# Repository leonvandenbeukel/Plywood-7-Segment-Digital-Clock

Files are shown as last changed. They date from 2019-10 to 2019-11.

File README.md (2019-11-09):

# Plywood 7 Segment Digital Clock

Design is done with [FreeCAD](https://www.freecadweb.org/) (Plywood-7-Segment-Digital-Clock.FCStd). This file contains all the source models for 3D printing and the paths for CNC machining (you might have to re-create the paths for your CNC machine but you can use the FreeCAD file for this). My paths are generated to use with a [GRBL](https://github.com/gnea/grbl/wiki) based machine.

## License

<br />This work is licensed under a <a rel="license" href="http://creativecommons.org/licenses/by-nc-sa/4.0/">Creative Commons Attribution-NonCommercial-ShareAlike 4.0 International License</a>.

## Schematic

Connect 5 volts from the micro usb breakout board to the 5 volt (VIN) pin on the ESP module.  
Connect Ground from the micro usb breakout board to the Ground on the ESP module.  
Connect 5 volts from the usb breakout board to 5 volt on the LED strip.  
Connect Ground from the usb breakout board to Ground on the LED strip.  
Connect pin D6 from the ESP module to the Data line on the LED strip.  
Connect pin D8 from the ESP module to one side of the button and connect the other side of the button to 3.3V of the ESP module.  

To power the clock you can use a regular 5V 2A power supply.

| Components                   |
| -------------                |
| ESP8266 Wi-Fi module         |
| USB break out board          |
| 5V 2A power supply           |
| Wires                        |
| Mini breadboard              |
| 58x WS2812B LED              |

## Indexes of LEDs (2 per segment):

Check the YouTube video for the order how to wire and solder them together because this is mirrored to the following diagram:

```

    47 46        33 32            17 16        3  2
  48     45    34     31        18     15    4      1
  49     44    35     30   29   19     14    5      0
    57 56        43 42            27 26       13 12
  50     55    36     41   28   20     25    6     11
  51     54    37     40        21     24    7     10 
    52 53        38 39            22 23        8  9
    
```

## YouTube video

<a href="https://youtu.be/EQGggxqPL-g" target="_blank">Click to view: Plywood Clock</a>

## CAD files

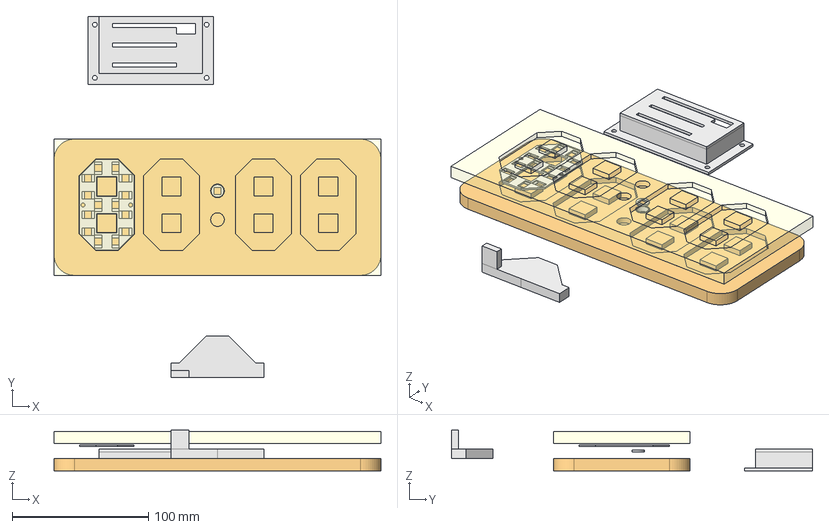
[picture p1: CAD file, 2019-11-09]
Plywood-7-Segment-Digital-Clock.FCStd
240.0 x 265.0 x 30.0 mm
Front panel
3DP dot insert
3DP dot back panel
3DP segments back panel
Board Mount
Back cover

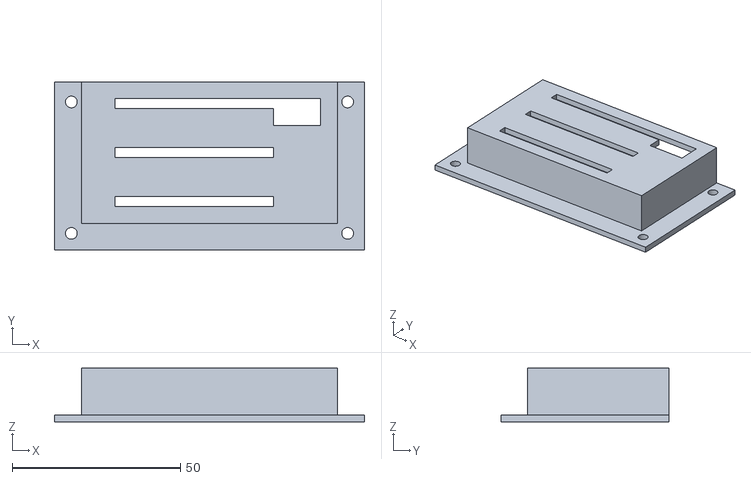
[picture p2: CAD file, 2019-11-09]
stl/board back panel.stl
92.0 x 50.0 x 16.0

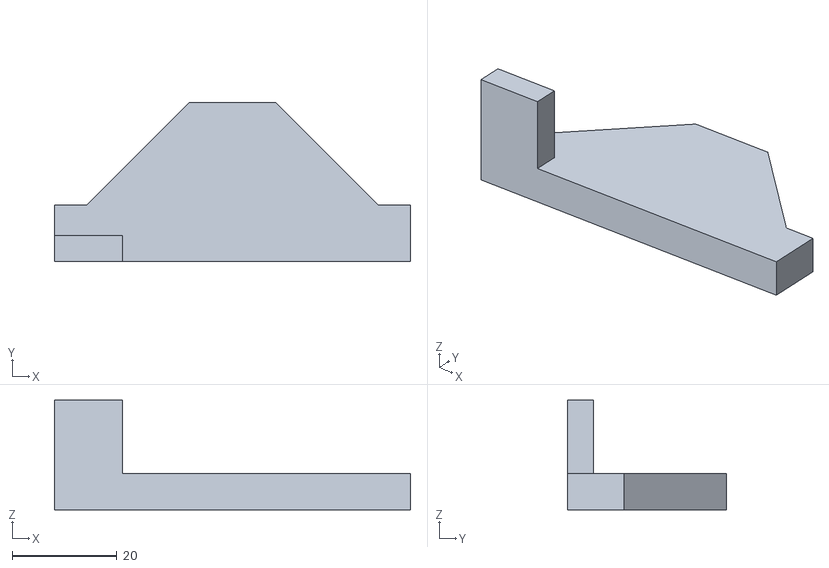
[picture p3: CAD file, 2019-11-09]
stl/board mount.stl
68.0 x 30.4 x 21.0

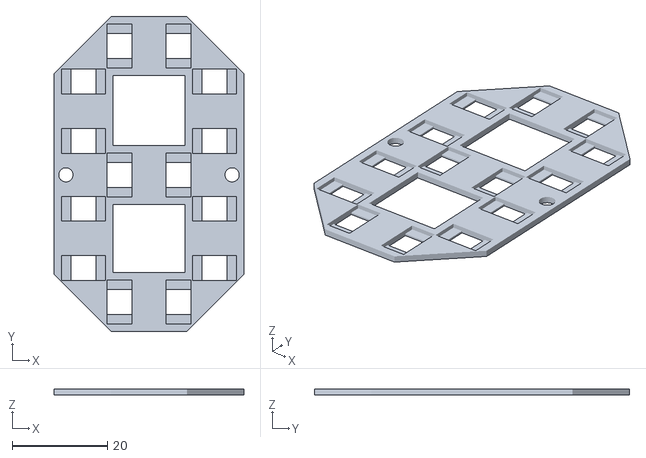
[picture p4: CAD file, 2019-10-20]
stl/segments back.stl
39.9 x 66.3 x 1.20

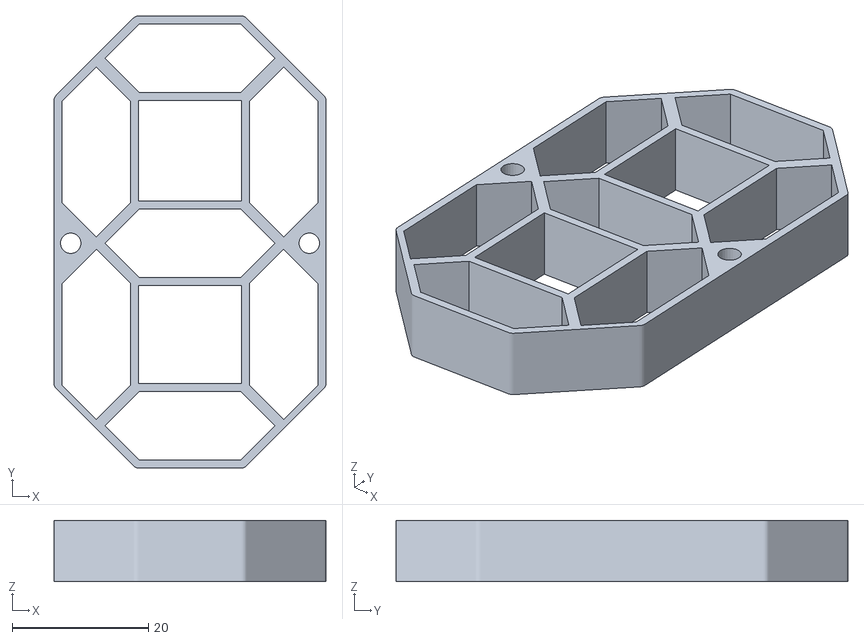
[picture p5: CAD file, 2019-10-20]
stl/segments.stl
39.9 x 66.3 x 9.00

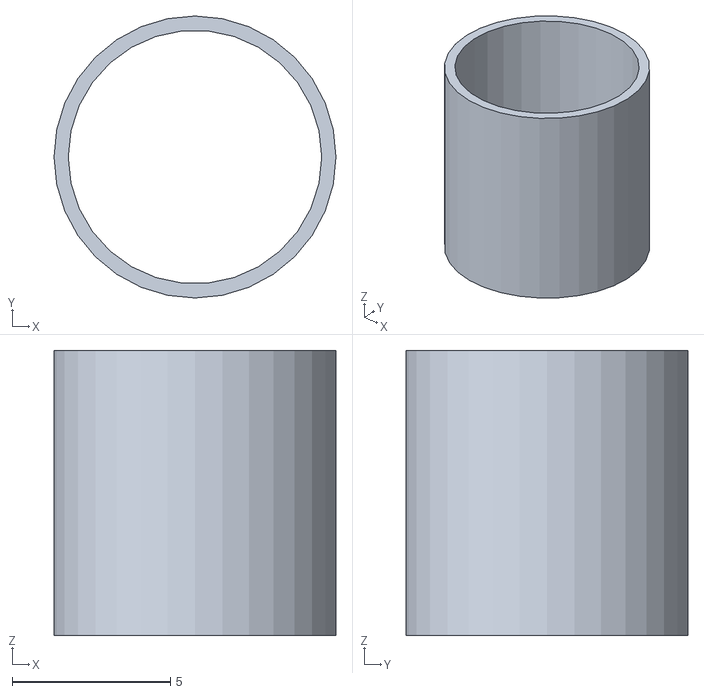
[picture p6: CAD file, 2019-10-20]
stl/dot insert.stl
8.90 x 8.90 x 9.00

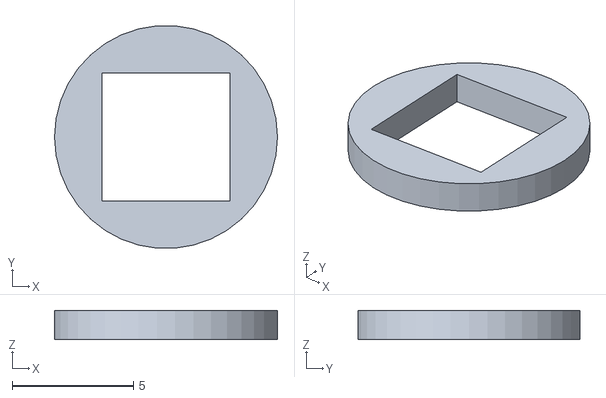
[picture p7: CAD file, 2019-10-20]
stl/dot insert back.stl
9.20 x 9.17 x 1.20

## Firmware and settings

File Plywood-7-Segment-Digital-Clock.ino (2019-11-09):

/*
  
 Leon van den Beukel - 2019 

 Licence: Attribution-NonCommercial-ShareAlike 4.0 International (CC BY-NC-SA 4.0) (https://creativecommons.org/licenses/by-nc-sa/4.0/)
    
*/

#include <ESP8266WiFi.h>
#include <WiFiClient.h>
#include <time.h>
#include <FastLED.h>
#include <EEPROM.h>

const char *WIFI_NETWORK_NAME = "***";              // Change to your wifi network name
const char *WIFI_PASSWORD = "***";                  // Change to your wifi password
float timeZone = 1.0;                               // Change this value to your local timezone (in my case +1 for Amsterdam)
const int DAY_LIGHT_OFFSET_SECONDS = 3600;          // Daylight saving

const char *TIME_SERVER = "pool.ntp.org";
const int EPOCH_1_1_2019 = 1546300800;
time_t now;

#define NUM_LEDS 58
#define DATA_PIN 6 
CRGB LEDs[NUM_LEDS];

byte nrOfLEDsPerSegment = 2;
void displayNumber(byte, byte);
void displayDots();

#define BTN_PIN D8

#define arr_len( x )  ( sizeof( x ) / sizeof( *x ) )
CRGB colors[] = {CRGB::Red, CRGB::RoyalBlue, CRGB::Green, CRGB::Yellow, CRGB::Magenta, CRGB::White, CRGB::Blue};
byte colorSize = arr_len(colors);
byte colorIndex = 0;
CRGB color = colors[colorIndex];

void setup() { 

  pinMode(BTN_PIN, INPUT);

  // Initialize LED strip
  FastLED.delay(2000);
  
  // Check if you're LED strip is a RGB or GRB version (third parameter)
  FastLED.addLeds<WS2812B, DATA_PIN, GRB>(LEDs, NUM_LEDS);

  Serial.begin(115200);          
  
  WiFi.begin(WIFI_NETWORK_NAME, WIFI_PASSWORD);

  while (WiFi.status() != WL_CONNECTED)
  {
    delay(500);
    Serial.print(".");
  }

  configTime(timeZone, DAY_LIGHT_OFFSET_SECONDS, TIME_SERVER);

  while (now < EPOCH_1_1_2019)
  {
    now = time(nullptr);
    delay(500);
    Serial.print("*");
  }

  // If color is stored previously, than restore
  EEPROM.begin(1);
  colorIndex = EEPROM.read(0);
  if (colorIndex >= 0) {
    color = colors[colorIndex];
    Serial.print("Previous color found: ");
    Serial.println(colorIndex);
  } else {
    Serial.print("Previous color not found: ");
    Serial.println(colorIndex);
  }
}

void loop() {

  int buttonState = digitalRead(BTN_PIN);
  if (buttonState == HIGH) {
    Serial.println("Button Pushed");
    colorIndex += 1;
    if (colorIndex >= colorSize)
      colorIndex = 0;
    
    color = colors[colorIndex];
    
    EEPROM.write(0, colorIndex); 
    EEPROM.end();
    Serial.print("Color index stored: ");
    Serial.println(colorIndex);  
  }

  struct tm *timeinfo;
  time(&now);
  timeinfo = localtime(&now);

  int hour = timeinfo->tm_hour;
  int mins = timeinfo->tm_min;

  byte h1 = hour / 10;
  byte h2 = hour % 10;
  byte m1 = mins / 10;
  byte m2 = mins % 10;

  displayDots();
  
  if (h1 > 0)
    displayNumber(h1,3);
    
  displayNumber(h2,2);
  displayNumber(m1,1);
  displayNumber(m2,0);

  delay(150);
}

void displayNumber(byte number, byte segment) {

  // segment from left to right: 3, 2, 1, 0
  byte startindex = 0;
  switch (segment) {
    case 0:
      startindex = 0;
      break;
    case 1:
      startindex = 14;
      break;
    case 2:
      startindex = 30;
      break;
    case 3:
      startindex = 44;
      break;    
  }

/*

Indexes of LEDs (2 per segment):

    47 46        33 32            17 16        3  2
  48     45    34     31        18     15    4      1
  49     44    35     30   29   19     14    5      0
    57 56        43 42            27 26       13 12
  50     55    36     41   28   20     25    6     11
  51     54    37     40        21     24    7     10 
    52 53        38 39            22 23        8  9
    
*/

  int numbers[] = {
    0b00111111111111,  // 0
    0b00110000000011,  // 1
    0b11001111001111,  // 2
    0b11111100001111,  // 3
    0b11110000110011,  // 4
    0b11111100111100,  // 5
    0b11111111111100,  // 6
    0b00110000001111,  // 7
    0b11111111111111,  // 8
    0b11111100111111,  // 9
    0b00000000000000,  // 10 off       
  };

  for (byte i=0; i<14; i++){
    LEDs[i + startindex] = ((numbers[number] & 1 << i) == 1 << i) ? color : CRGB::Black;
  }

  FastLED.show();  
}

void allOff() {

  for (int i=0; i<NUM_LEDS; i++){
    LEDs[i] = CRGB::Black;
  }
  FastLED.show();
  
}

void allOn(CRGB color) {

  for (int i=0; i<NUM_LEDS; i++){
    LEDs[i] = color;
  }
  FastLED.show();
  
}

void displayDots() {
   LEDs[28] = color;
   LEDs[29] = color;    
   FastLED.show();
}

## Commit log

2019-10-19 Added FreeCAD file
    [Plywood-7-Segment-Digital-Clock.FCStd]
2019-10-19 Updated file
    [Plywood-7-Segment-Digital-Clock.FCStd]
2019-10-20 Added stl files
    [dot insert back.stl, dot insert.stl, segments back.stl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]
2019-10-20 Added gcode for back rings and updated segments back
    [Plywood-7-Segment-Digital-Clock.FCStd]
2019-10-25 Changed toolpath for backpanels cutout
    [Plywood-7-Segment-Digital-Clock.FCStd]
2019-10-25 Added BackPanel and CNC job
    [Plywood-7-Segment-Digital-Clock.FCStd]
2019-11-01 Added first Arduino code and added gcode for backpanel contour
    [Plywood-7-Segment-Digital-Clock.FCStd]
2019-11-09 Added back panels
    [Plywood-7-Segment-Digital-Clock.FCStd, board back panel.stl, board mount.stl]
